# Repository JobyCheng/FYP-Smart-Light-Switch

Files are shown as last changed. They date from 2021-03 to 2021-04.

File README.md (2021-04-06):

# FYP - Smart Light Switch

This is the repo for Group SS04a-20 Final Year Project.

`/Switch` contain the PlatformIO project file for the esp32 development board.

`/model` contain file related to the 3D-model for this project.

`/video` contain demo video of the product.

`node-red-config` contain JSON file for node-red

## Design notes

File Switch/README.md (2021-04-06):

# Smart Light Switch
This is a sum up file. Please update it if anything is implemented or need to be implement.

Run `python localServer.py` to have a look on the web page without any post and get function.

css may not update beacuse of cache. Press `ctrl+F5` for most window browser. `cmd+F5` for mac (not sure)

*avoid using ADC2 (Wifi use ADC2) (not checked) (from https://github.com/khoih-prog/ESPAsync_WiFiManager)*

# Feature

- [x] Access Point (when not connected to a wifi server)
- [x] DNS ( problem exist, solve it later ) (only resolve address with Suffix `.local`(?))
- [x] WIfi client
- [x] mDNS
- [x] Mobile view
- [x] Changing the Access Point password
- [x] Wifi Page ( Fishished the fundimental part, but the UI is bad )
- [x] Reset all the setting ( by entering http://esp32.local/reset with connected device )
- [x] HOME Page
- [x] Multi Switch control 
- [x] time synchronization
- [x] time scheduled task

## Time schedule method
use cron-like syntax
```
second minute hour day month weekday action
```
To simpify the case for user interface, we will change `minute`, `hour` and `action` only.

## AP Sleep
Currently ESP32 AP doesn’t support all of the power save feature defined in Wi-Fi specification. To be specific, the AP only caches unicast data for the stations connect to this AP, but doesn’t cache the multicast data for the stations. If stations connected to the ESP32 AP are power save enabled, they may experience multicast packet loss.

https://docs.espressif.com/projects/esp-idf/en/latest/esp32/api-guides/wifi.html?highlight=power%20saving

https://blog.csdn.net/Naisu_kun/article/details/86300456
http://www.iotsharing.com/2017/05/tcp-udp-ip-with-esp32.html

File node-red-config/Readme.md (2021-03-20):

# node-red config
Change the address of TX to your network boardcast address

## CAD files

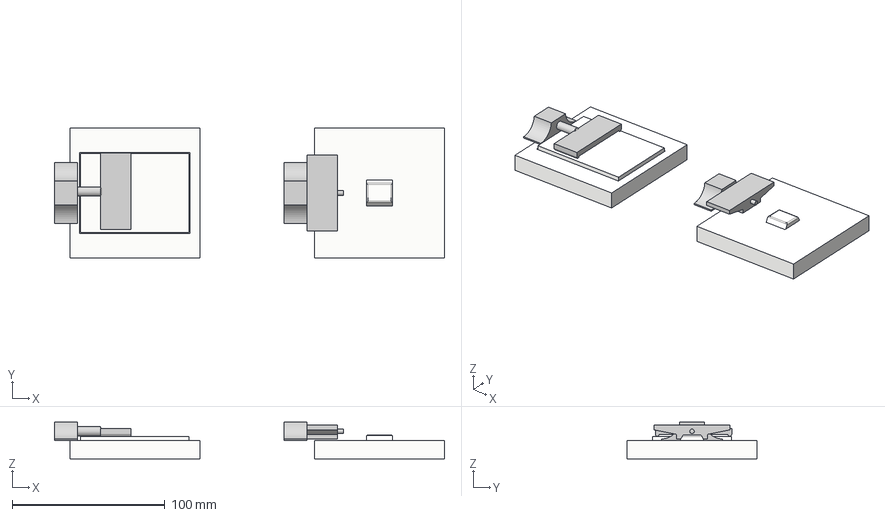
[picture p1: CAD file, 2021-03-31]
model/step&f3d/Task4.step
255.0 x 85.0 x 24.0 mm
panel
Button
Base x 2
panel_1
button_1
Moving Part_1
Moving Part_2

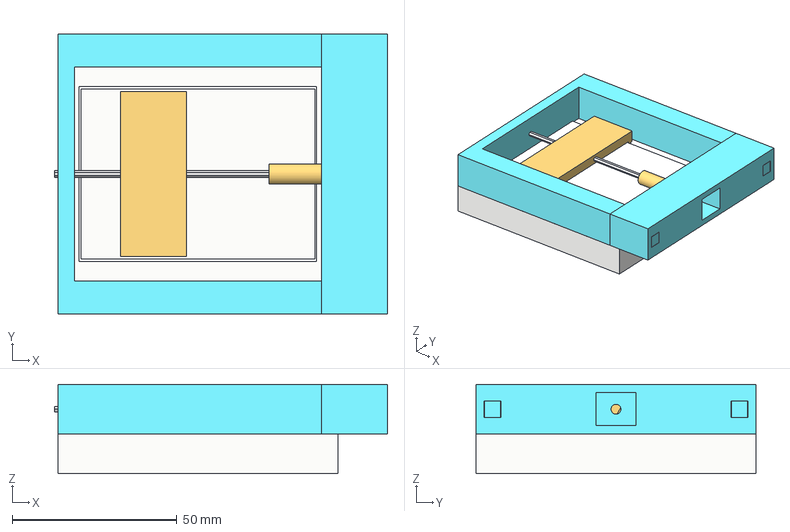
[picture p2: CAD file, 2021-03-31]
model/step&f3d/Task2-3.step
101.0 x 85.0 x 27.0 mm
Lever
panel
Button
shaft
Frame
Converter

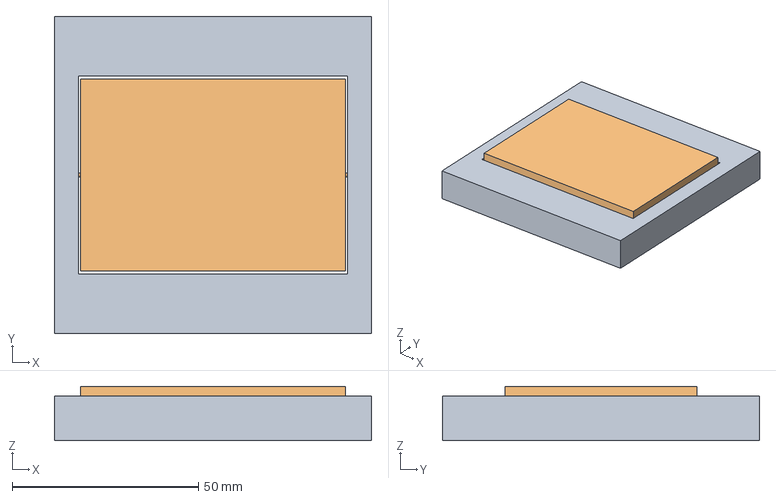
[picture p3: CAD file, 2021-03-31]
model/step&f3d/EU_switch.step
85.0 x 85.0 x 14.5 mm
panel
Button

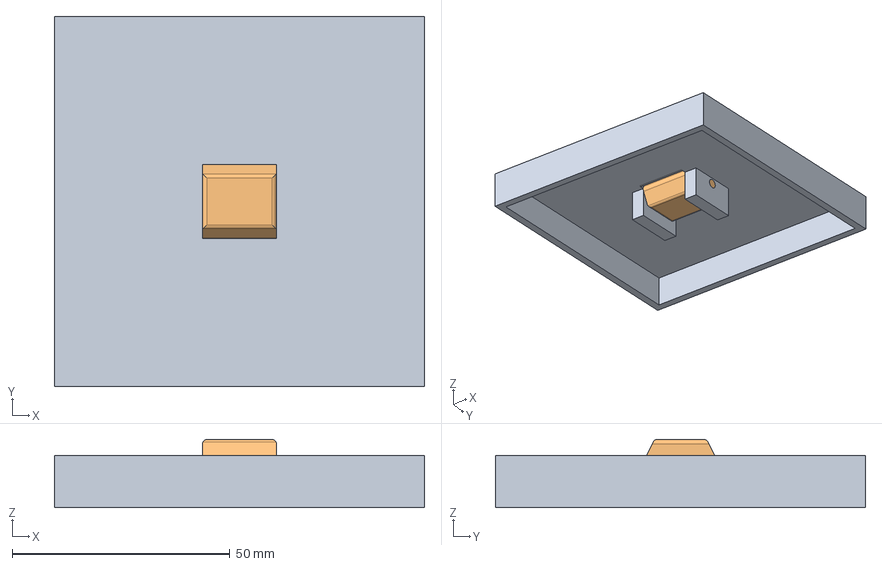
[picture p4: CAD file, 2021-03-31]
model/step&f3d/AU_switch.step
85.0 x 85.0 x 15.6 mm
panel
button

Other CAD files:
model/step&f3d/AU_switch.f3d
model/step&f3d/EU_switch.f3d
model/step&f3d/Task2-3.f3z
model/step&f3d/Task4.f3z

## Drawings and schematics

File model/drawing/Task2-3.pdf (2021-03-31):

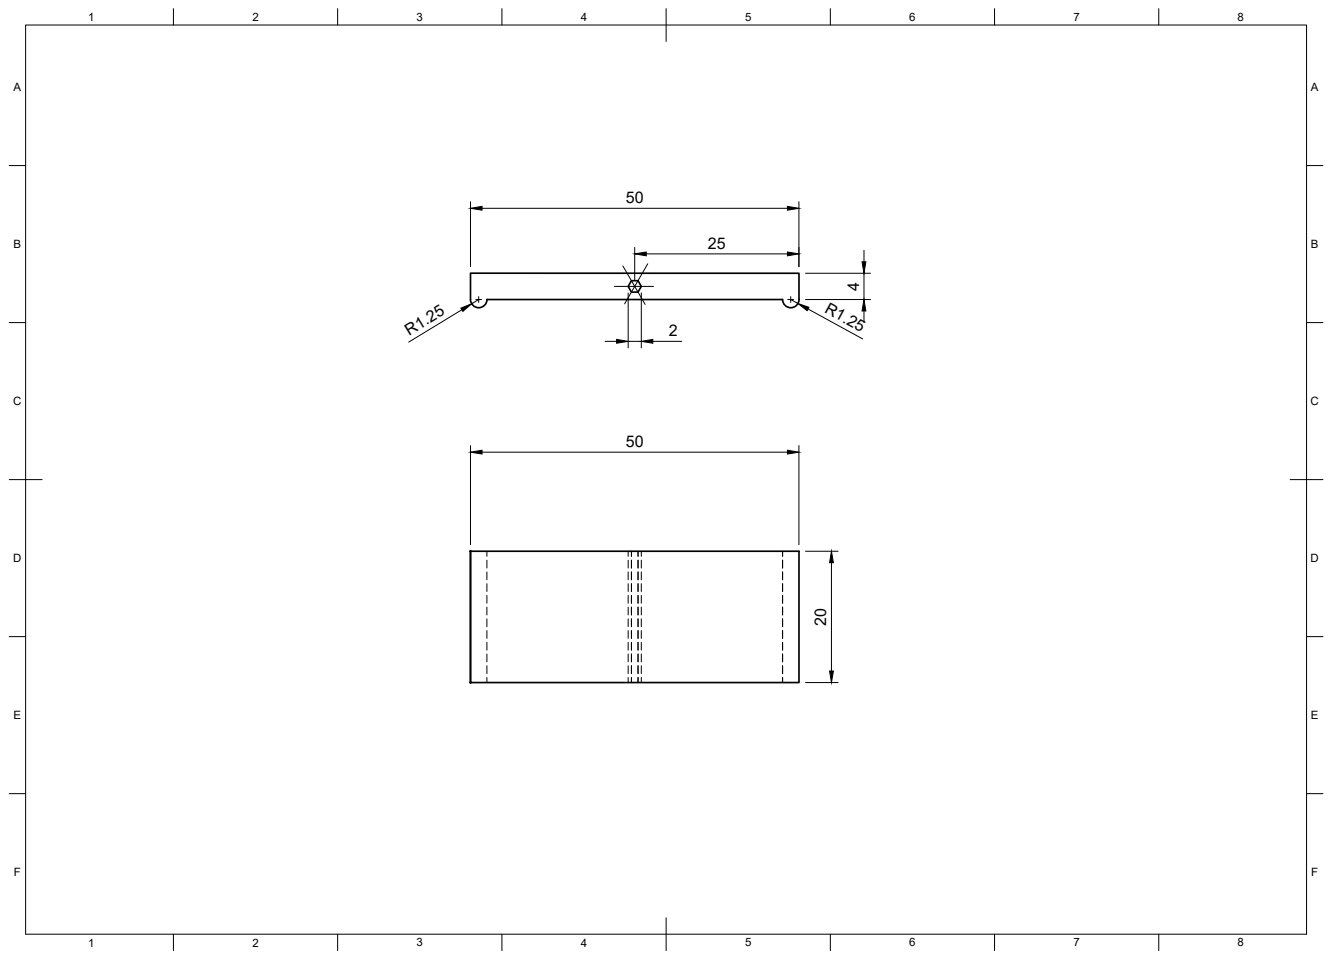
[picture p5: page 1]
8 BCDEF; ABCDEF

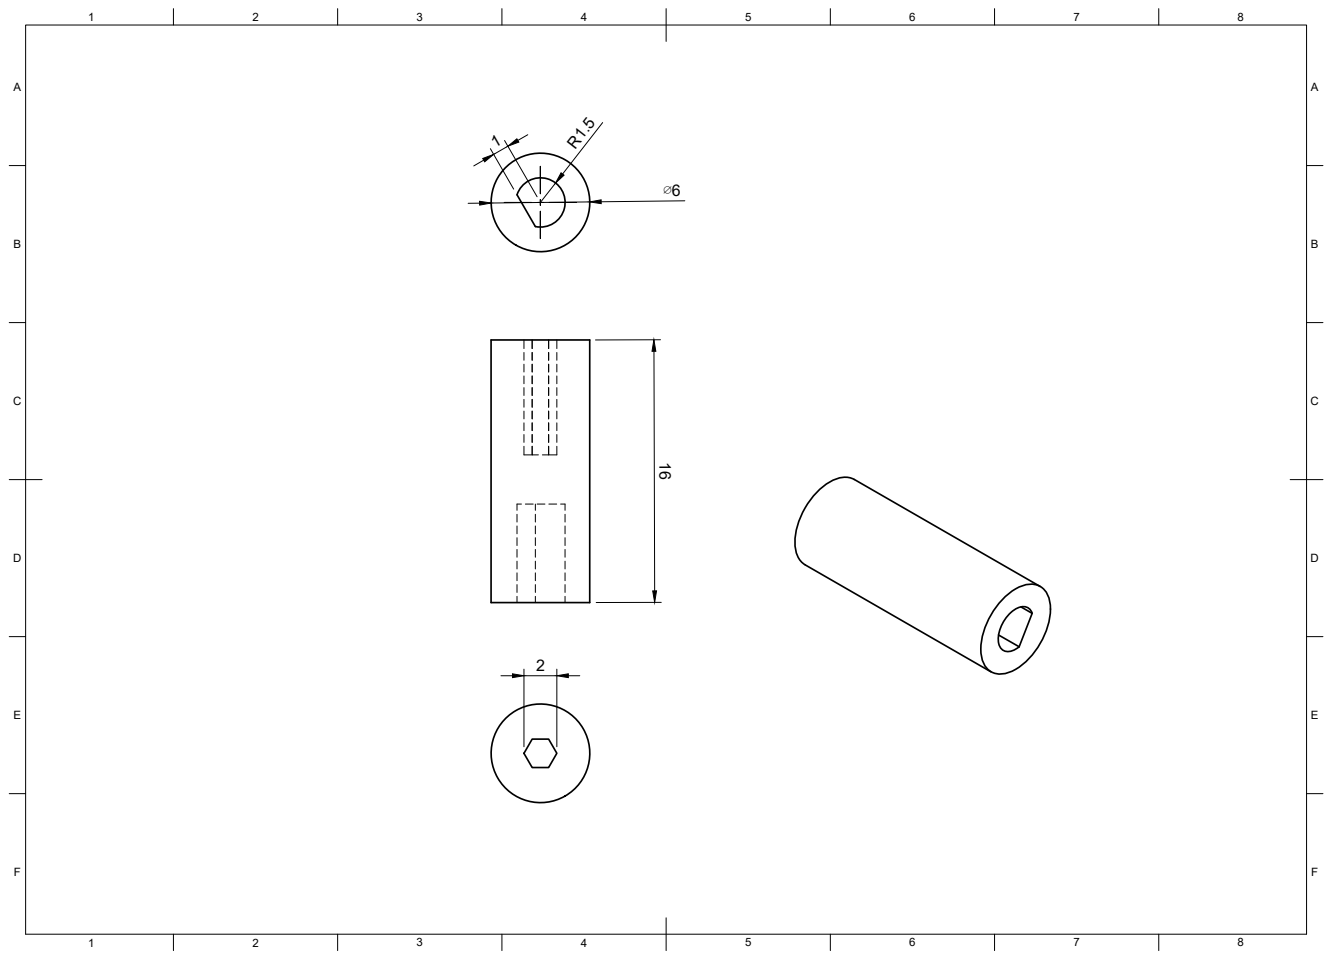
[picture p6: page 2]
8 BCDEF; ABCDEF R1.5

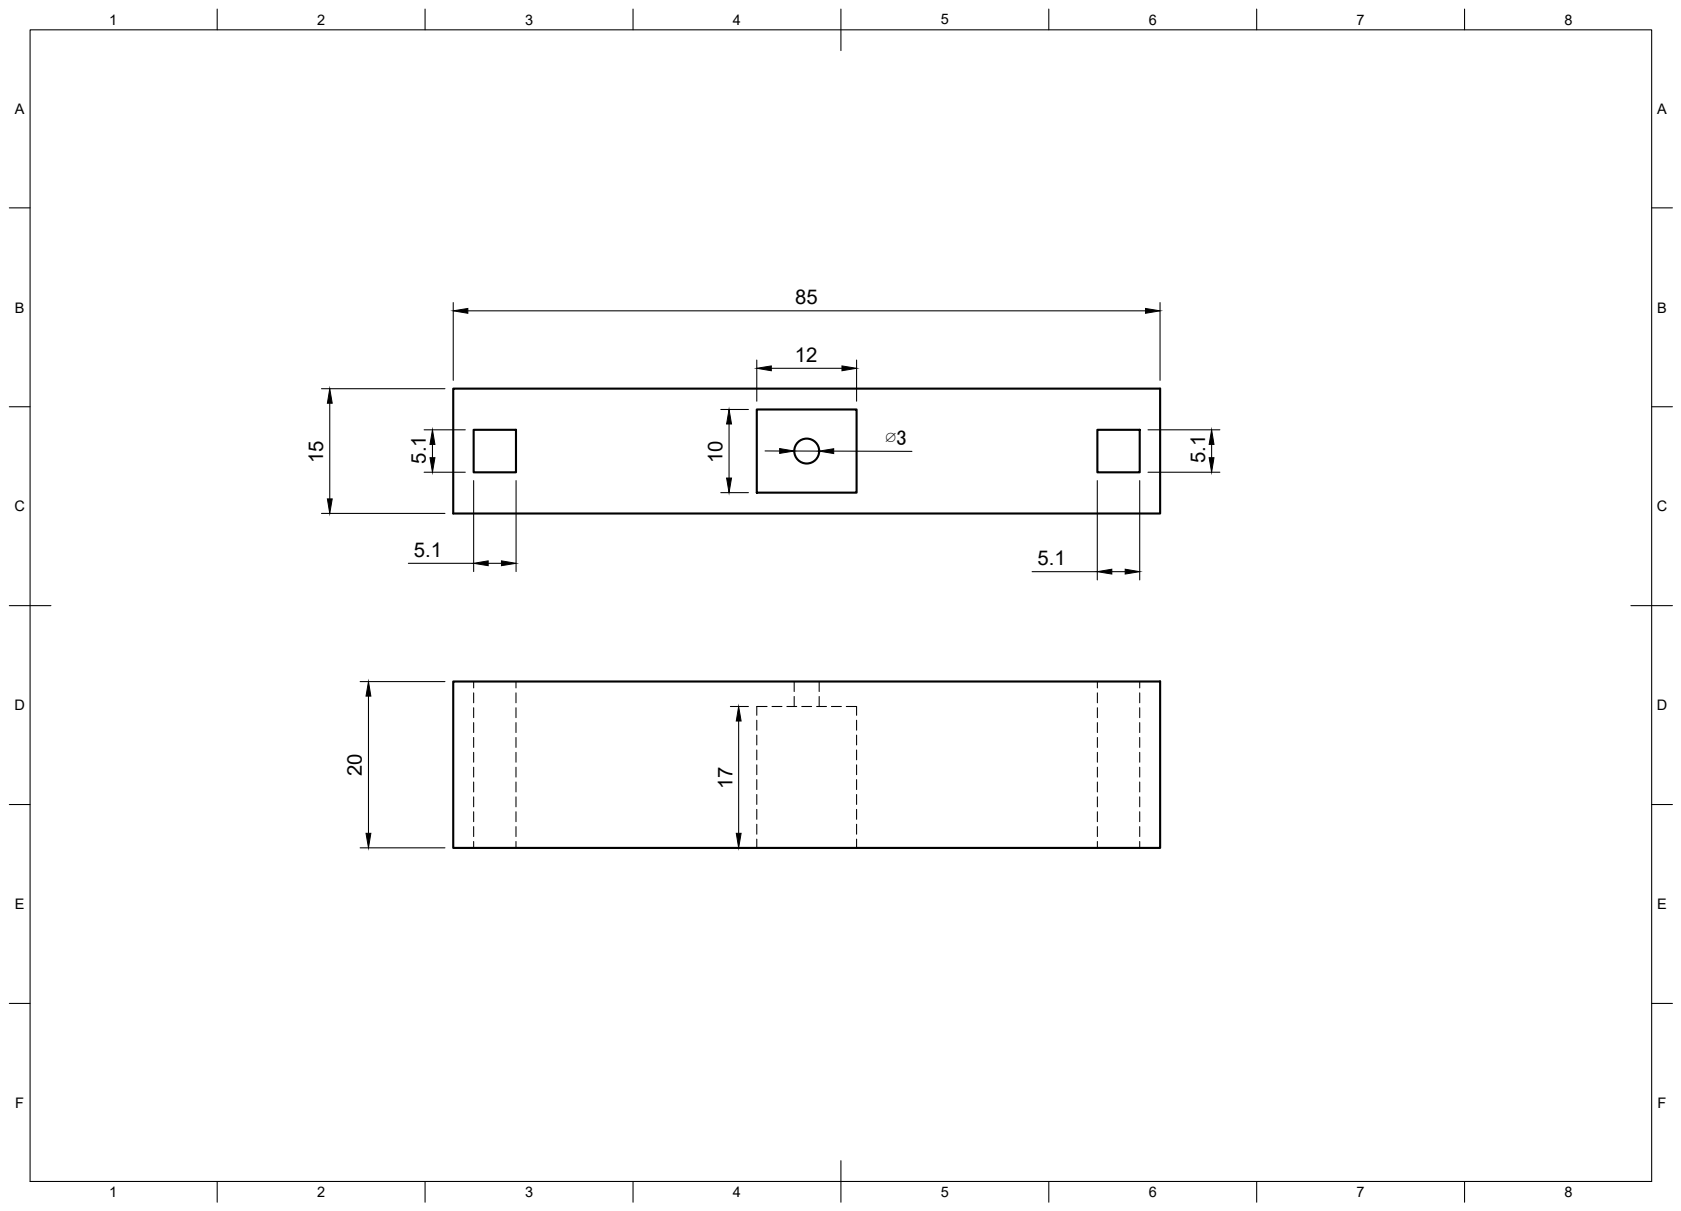
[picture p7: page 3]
8 BCDEF; ABCDEF

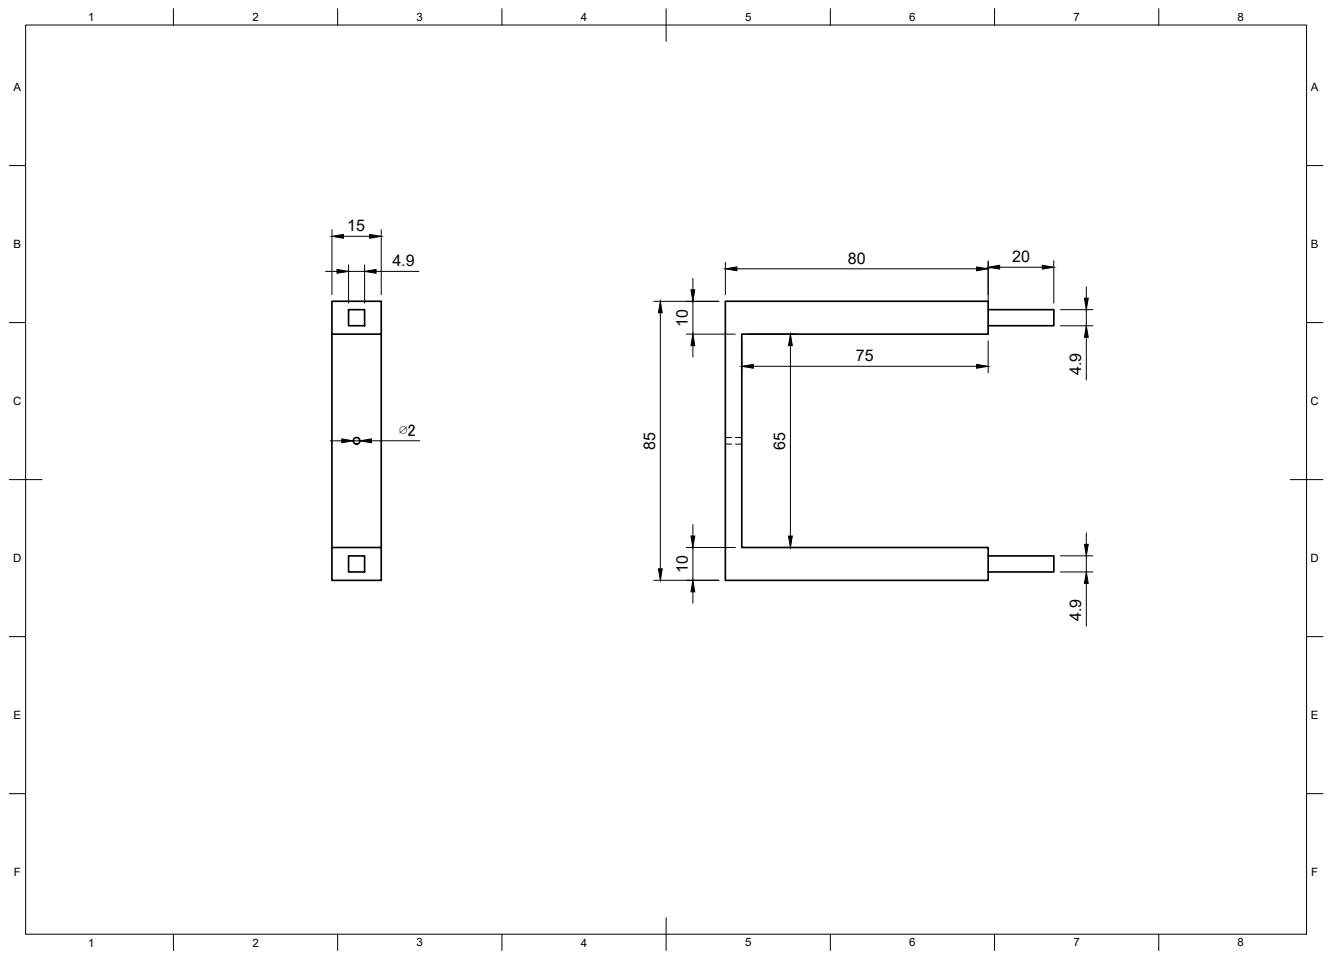
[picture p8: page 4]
8 BCDEF; ABCDEF 85

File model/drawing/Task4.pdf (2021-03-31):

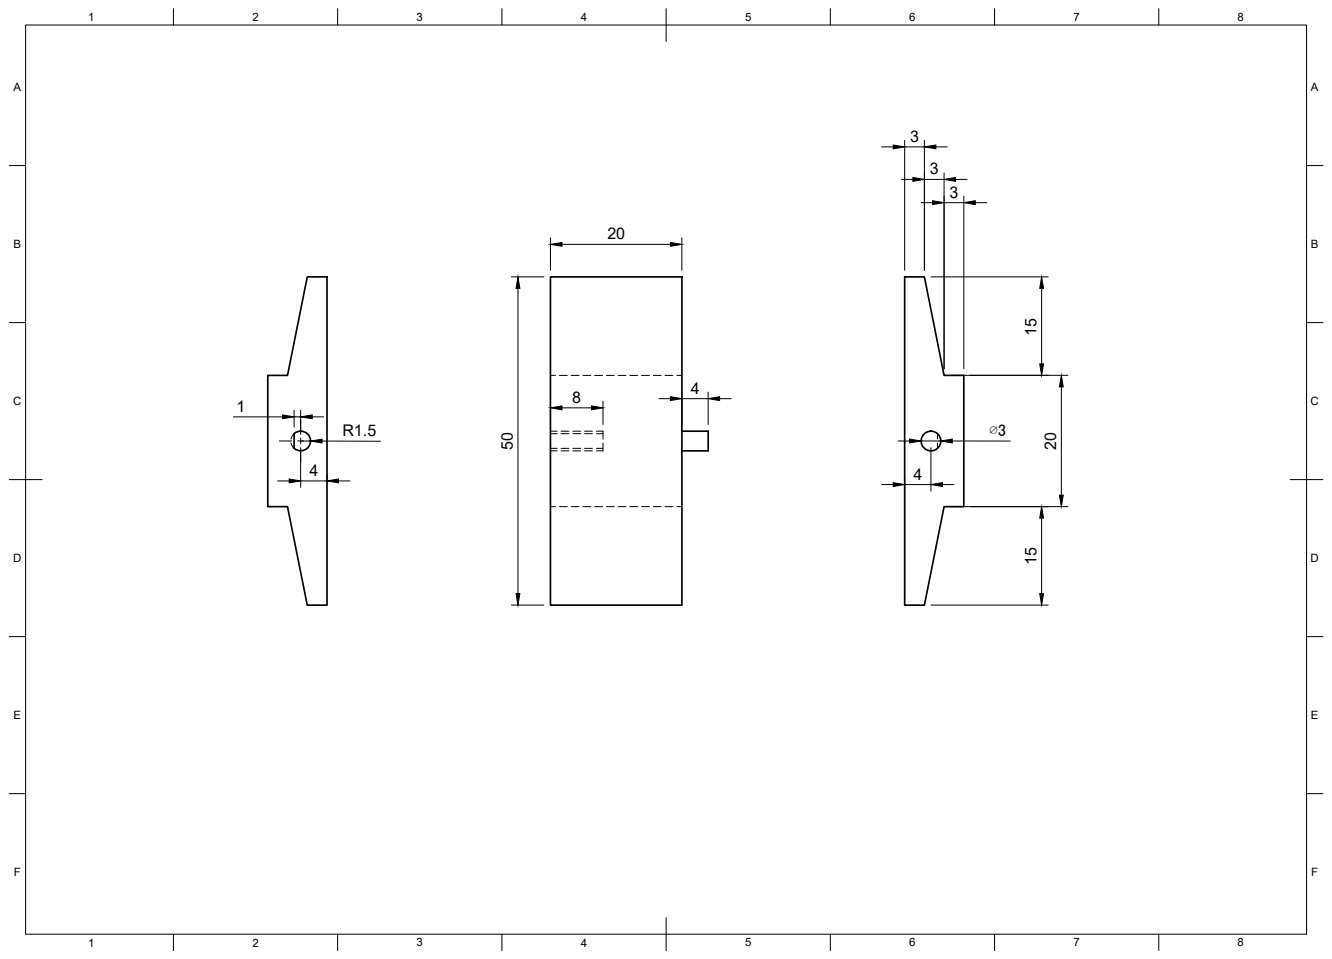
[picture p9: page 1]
8 BCDEF; ABCDEF

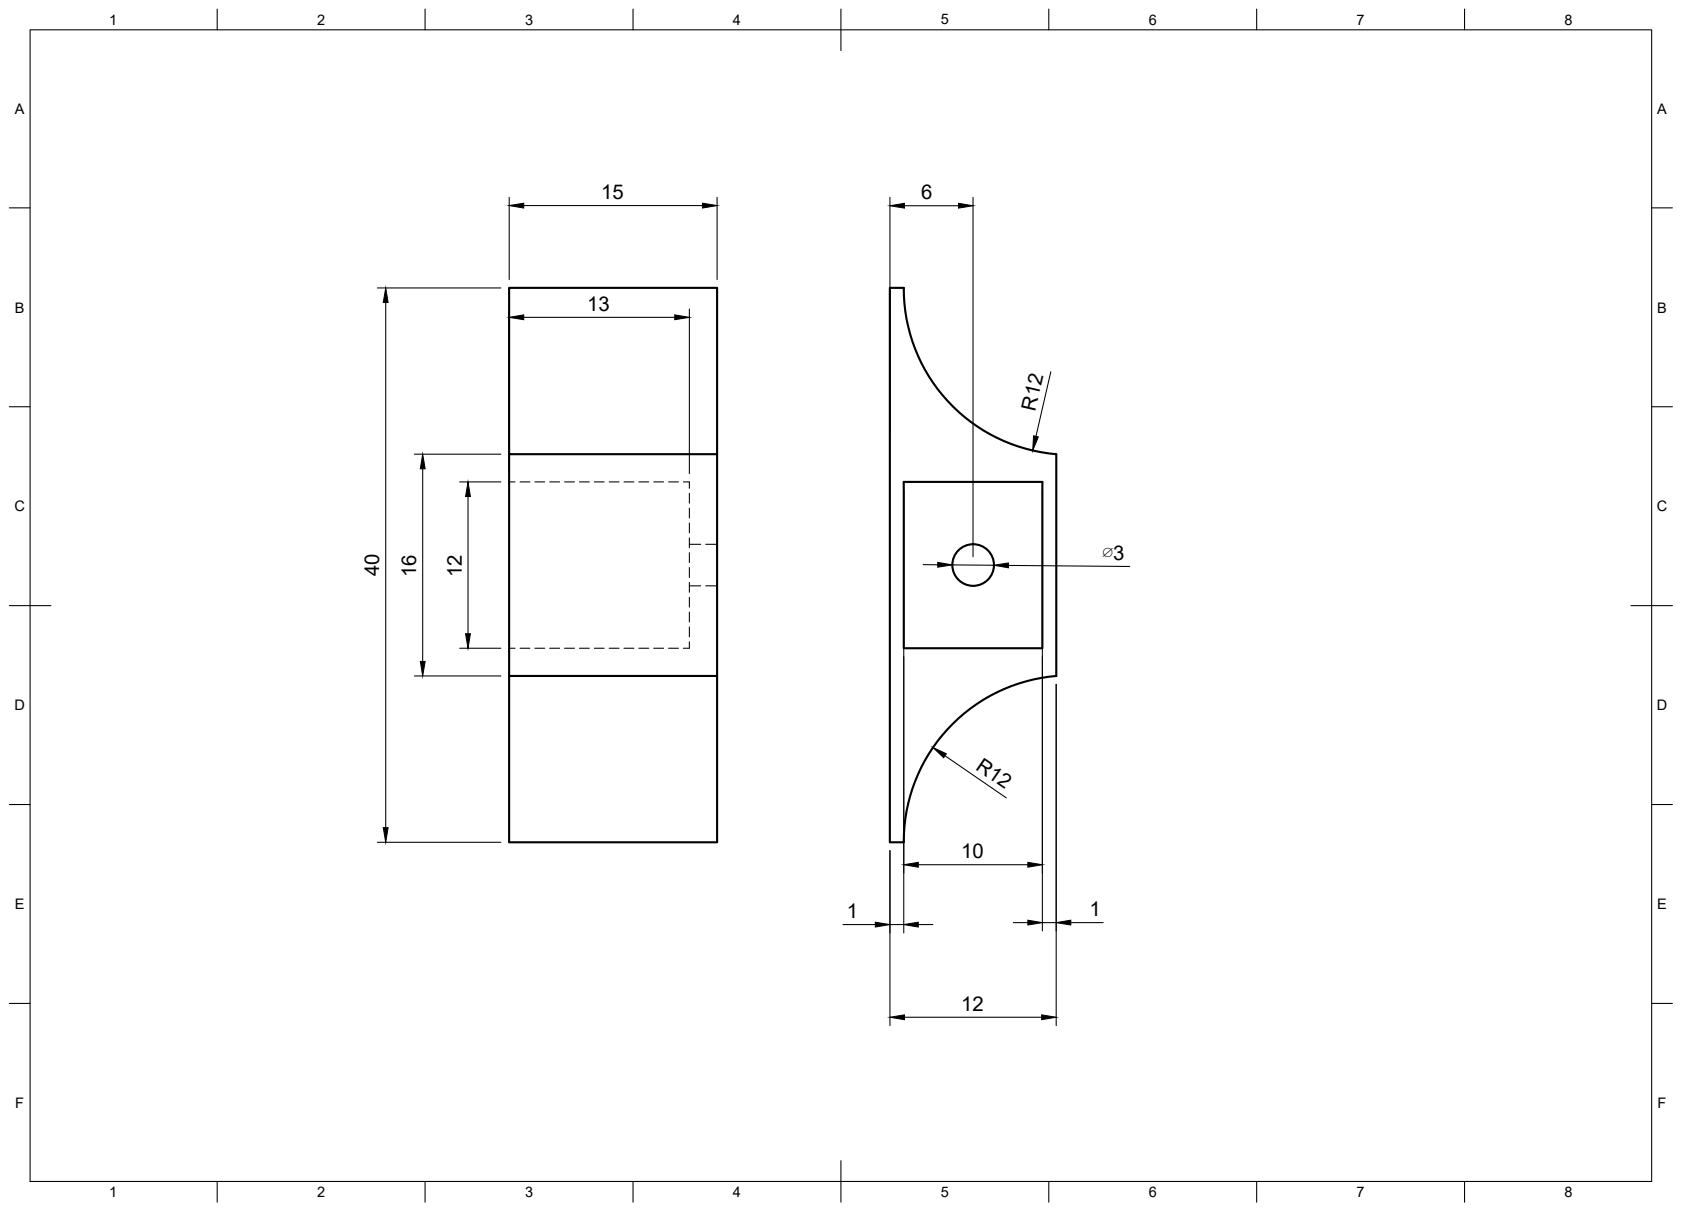
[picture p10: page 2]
8 BCDEF; ABCDEF

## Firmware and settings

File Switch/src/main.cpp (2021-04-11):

#include <Arduino.h>
#include <SPIFFS.h>

#include <Preferences.h>
#include <HTTPClient.h>

#include "service_mDNS.h"
#include "service_DNS.h"
#include "service_Wifi_AP.h"
#include "service_time_sync.h"
#include "service_cron.h"
#include "service_Wifi_client.h"
#include "service_udp.h"
#include "struct_client_entry.h"

#include <ESPAsyncWebServer.h>
#include "responses.h"

#include <CronAlarms.h>

#include "switch_gy25z.h"
#include "switch_touch.h"
#include "switch_motor.h"

/*
██╗   ██╗ █████╗ ██████╗ ██╗ █████╗ ██████╗ ██╗     ███████╗
██║   ██║██╔══██╗██╔══██╗██║██╔══██╗██╔══██╗██║     ██╔════╝
██║   ██║███████║██████╔╝██║███████║██████╔╝██║     █████╗
╚██╗ ██╔╝██╔══██║██╔══██╗██║██╔══██║██╔══██╗██║     ██╔══╝
 ╚████╔╝ ██║  ██║██║  ██║██║██║  ██║██████╔╝███████╗███████╗
  ╚═══╝  ╚═╝  ╚═╝╚═╝  ╚═╝╚═╝╚═╝  ╚═╝╚═════╝ ╚══════╝╚══════╝

*/
// product name
// will be used in name of access point, domain name of site

String PRODUCT_NAME = "esp32";

std::vector<client_entry> client_list;

enum ROLE{SERVER,CLIENT} role;
String DEVICE_ID;
String LABEL;
String MAC_ADDR;

AsyncWebServer web_server(80);
Preferences preferences;
DNSServer dns_server;
extern CronClass Cron;
extern WiFiClass WiFi;
WiFiUDP udp;

bool DNS_enabled;

unsigned long lastLoop;

/*
███████╗███████╗████████╗██╗   ██╗██████╗
██╔════╝██╔════╝╚══██╔══╝██║   ██║██╔══██╗
███████╗█████╗     ██║   ██║   ██║██████╔╝
╚════██║██╔══╝     ██║   ██║   ██║██╔═══╝
███████║███████╗   ██║   ╚██████╔╝██║
╚══════╝╚══════╝   ╚═╝    ╚═════╝ ╚═╝

*/
void setup() {
  Serial.begin(115200);
  // put your setup code here, to run once:

  pinMode(AIN1, OUTPUT);
  pinMode(AIN2, OUTPUT);
  pinMode(EN, OUTPUT);

  touchAttachInterrupt(T8, T8wasActivated, threshold);
  touchAttachInterrupt(T9, T9wasActivated, threshold);

  gy25z_init();

  preferences.begin("switchSetting");
  preferences.putBool("switchIsOn", false);
  preferences.putBool("calibrated", false);
  preferences.end();
  
  // create a id with MAC address.
  MAC_ADDR = String((unsigned long) ESP.getEfuseMac(),16);
  DEVICE_ID = MAC_ADDR;

  // get label if any
  preferences.begin("setting");
  LABEL = preferences.isKey("LABEL")?preferences.getString("LABEL"):String(DEVICE_ID);
  preferences.end();
  // Default as server, change to client if it detect a server.
  role = SERVER;

  /*
  ███╗   ██╗███████╗████████╗██╗    ██╗ ██████╗ ██████╗ ██╗  ██╗
  ████╗  ██║██╔════╝╚══██╔══╝██║    ██║██╔═══██╗██╔══██╗██║ ██╔╝
  ██╔██╗ ██║█████╗     ██║   ██║ █╗ ██║██║   ██║██████╔╝█████╔╝
  ██║╚██╗██║██╔══╝     ██║   ██║███╗██║██║   ██║██╔══██╗██╔═██╗
  ██║ ╚████║███████╗   ██║   ╚███╔███╔╝╚██████╔╝██║  ██║██║  ██╗
  ╚═╝  ╚═══╝╚══════╝   ╚═╝    ╚══╝╚══╝  ╚═════╝ ╚═╝  ╚═╝╚═╝  ╚═╝
  */
  

  // Wifi
  if (wifi_client_start_with_setting()){
    // Check if there is any server in the LAN
    if (udp_start()){
      if(udp_checkServer(2000)){
        Serial.println("Server found");
        udp_stop();
        role = CLIENT;
      }else{
        // keep listening to port 8000
        mDNS_start(PRODUCT_NAME);
      }
    }

    Serial.println("Role:\t\t"+((role == CLIENT)?String("Client"):String("Server")));
    Serial.println("ID:\t\t"+DEVICE_ID);
    Serial.println("label:\t\t"+LABEL);
    
    if(time_sync_start()){  // Start cron if time sync is check.
      cron_load_from_setting();
    }
    
  }else{
    //Access point
    wifi_ap_start(PRODUCT_NAME+"-"+DEVICE_ID);
    //DNS
    DNS_enabled = DNS_start("*", WiFi.softAPIP());
    //if(DNS_enabled){t_DNS_request.enable();}
  }

  client_list.push_back({DEVICE_ID,LABEL,WiFi.localIP()});


  /*
  ██╗    ██╗███████╗██████╗ ███████╗███████╗██████╗ ██╗   ██╗███████╗██████╗
  ██║    ██║██╔════╝██╔══██╗██╔════╝██╔════╝██╔══██╗██║   ██║██╔════╝██╔══██╗
  ██║ █╗ ██║█████╗  ██████╔╝███████╗█████╗  ██████╔╝██║   ██║█████╗  ██████╔╝
  ██║███╗██║██╔══╝  ██╔══██╗╚════██║██╔══╝  ██╔══██╗╚██╗ ██╔╝██╔══╝  ██╔══██╗
  ╚███╔███╔╝███████╗██████╔╝███████║███████╗██║  ██║ ╚████╔╝ ███████╗██║  ██║
   ╚══╝╚══╝ ╚══════╝╚═════╝ ╚══════╝╚══════╝╚═╝  ╚═╝  ╚═══╝  ╚══════╝╚═╝  ╚═╝
  */
  
  if(!SPIFFS.begin(true)){
    Serial.println("An Error has occurred while mounting SPIFFS");
    return;
  }
  
  /*
  ██████╗ ███████╗ ██████╗ ██╗   ██╗███████╗███████╗████████╗
  ██╔══██╗██╔════╝██╔═══██╗██║   ██║██╔════╝██╔════╝╚══██╔══╝
  ██████╔╝█████╗  ██║   ██║██║   ██║█████╗  ███████╗   ██║
  ██╔══██╗██╔══╝  ██║▄▄ ██║██║   ██║██╔══╝  ╚════██║   ██║
  ██║  ██║███████╗╚██████╔╝╚██████╔╝███████╗███████║   ██║
  ╚═╝  ╚═╝╚══════╝ ╚══▀▀═╝  ╚═════╝ ╚══════╝╚══════╝   ╚═╝
  */

 if(role == SERVER){
  web_server.serveStatic("/", SPIFFS, "/").setDefaultFile("index.html");

  web_server.on("/wifiStauts",HTTP_GET,responses_wifiStauts);
  web_server.on("/SSIDlist", HTTP_GET,responses_SSIDlist);
  web_server.on("/wifi_setting",HTTP_POST,responses_wifi_setting);
   
  web_server.on("/getClient",HTTP_GET,responses_getClient);
 }

  web_server.on("/reset",HTTP_GET,responses_reset);
  web_server.on("/restart",HTTP_GET,responses_restart);

  web_server.on("/on",HTTP_GET,responses_on);
  web_server.on("/off",HTTP_GET,responses_off);

  web_server.on("/getSchedule",HTTP_GET,responses_getSchedule);
  web_server.on("/setSchedule",HTTP_POST,responses_setSchedule);

  web_server.on("/status",HTTP_GET,responses_status);
  web_server.on("/setLabel",HTTP_GET,responses_setLabel);

  web_server.on("/calibration",HTTP_GET,responses_calibration);  

  web_server.begin();
  
  lastLoop = millis();
}

/*
██╗      ██████╗  ██████╗ ██████╗
██║     ██╔═══██╗██╔═══██╗██╔══██╗
██║     ██║   ██║██║   ██║██████╔╝
██║     ██║   ██║██║   ██║██╔═══╝
███████╗╚██████╔╝╚██████╔╝██║
╚══════╝ ╚═════╝  ╚═════╝ ╚═╝

*/
void loop() {
  // put your main code here, to run repeatedly:
  Cron.delay();
  if (DNS_enabled){dns_server.processNextRequest();};
  if (role==SERVER && WiFi.isConnected()){udp_handle_next_packet();}
  if (role==CLIENT && (millis()>lastLoop+1000*60)){udp_boardcast_message();lastLoop=millis();}
  touch_manual();
}

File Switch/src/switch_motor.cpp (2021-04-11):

#include "switch_motor.h"


const int AIN1 = 25; 
const int AIN2 = 26; 
const int EN = 27;
volatile float T8Roll;
volatile float T9Roll;
bool calManual = false;


//clk = t8
//anticlk = t9

void on(){
    //Serial.print("Switch On");
    
    preferences.begin("switchSetting"); 
    if(preferences.getBool("T8IsOn", false)){
        turnClkwise();
    }else{
        turnAntiClkwise();
    }
    preferences.end();
}

void off(){
    //Serial.print("off");

    preferences.begin("switchSetting");
    if(preferences.getBool("T8IsOn", false)){
        turnAntiClkwise();
    }else{
        turnClkwise();
    }
    preferences.end();
}

void calibrate(){
    //Serial.println("test");
    delay(700);
    bool cal = true;
    bool calT8 = false;
    bool calT9 = false;
    digitalWrite(EN, HIGH);
    while (cal){
        if(triggeredT8 && !triggeredT9){
            //Serial.println("T8");
            digitalWrite(AIN1, LOW);
            digitalWrite(AIN2, HIGH);
            if(touchRead(T8)>threshold){
                digitalWrite(AIN1, LOW);
                digitalWrite(AIN2, LOW);
                triggeredT8 = false;
                calT8 = true;
                T8Roll = gy25z_getRoll();
                delay(50);
            }
        }
        if(triggeredT9 && !triggeredT8){
            //Serial.println("T9");
            digitalWrite(AIN1, HIGH);
            digitalWrite(AIN2, LOW);
            if(touchRead(T9)>threshold){
                digitalWrite(AIN1, LOW);
                digitalWrite(AIN2, LOW);
                triggeredT9 = false;
                calT9 = true;
                T9Roll = gy25z_getRoll();
                delay(50);
            }
        }
        if(calT8 && calT9){
            delay(1);
            digitalWrite(EN, LOW);
            preferences.begin("switchSetting");
            preferences.putFloat("T8Roll",T8Roll);
            preferences.putFloat("T9Roll",T9Roll);
            if(T8Roll > T9Roll){
                preferences.putBool("T8IsOn",true);
            }else{
                preferences.putBool("T8IsOn",false);
            }
            delay(1);
            Serial.print("T8Roll: "); 
            Serial.println(preferences.getFloat("T8Roll",-1));
            Serial.print("T9Roll: "); 
            Serial.println(preferences.getFloat("T9Roll",-1));
            Serial.print("T8IsOn:" );
            Serial.println(preferences.getBool("T8IsOn", false)?String("True"):String("False"));
            preferences.putBool("calibrated",true);
            preferences.end();
            
            cal = false;
            calManual = true;
            Serial.println("end cal");
        }
    }
    return;
}

void turnClkwise(){
    preferences.begin("switchSetting");
    if(preferences.getBool("calibrated",false)){
        preferences.putBool("switchIsOn", (preferences.getBool("T8IsOn", false)?true:false));
        digitalWrite(EN, HIGH);
        float current_roll = gy25z_getRoll();
        float target_roll = preferences.getFloat("T8Roll",-1);
        digitalWrite(AIN1, LOW);
            digitalWrite(AIN2, HIGH);
        if(abs(current_roll - target_roll)<=2){
            digitalWrite(EN, LOW);
        }
    }else{
        Serial.println("Plz calibrate first");
    }
    preferences.end();
}

void turnAntiClkwise(){
    preferences.begin("switchSetting");
    if(preferences.getBool("calibrated",false)){
        preferences.putBool("switchIsOn", (preferences.getBool("T8IsOn", false)?false:true));
        digitalWrite(EN, HIGH);
        float current_roll = gy25z_getRoll();
        float target_roll = preferences.getFloat("T9Roll",-1);
        digitalWrite(AIN1, HIGH);
        digitalWrite(AIN2, LOW);
        if(abs(current_roll - target_roll)<=2){
            digitalWrite(EN, LOW);
        }
    }else{
        Serial.println("Plz calibrate first");
    }
    preferences.end();
}

void touch_manual() {
  if (triggeredT8 && calManual){
    triggeredT8 = false;
    if (touchIntervalComp(lastT8)){
      //Serial.println("turn anticlkwise");
      turnClkwise();
      lastT8 = millis();
    }
  }

  if (triggeredT9 && calManual){
    triggeredT9 = false;
    if (touchIntervalComp(lastT9)){
      //Serial.println("turn clkwise");
      turnAntiClkwise();
      lastT9 = millis();
    }
  }
}

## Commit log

2021-02-15 Add lines for power saving and restart machine
2021-02-24 Adding the switch table on the web site
2021-02-25 Force platformIO to use the v3.3 framework & fix problem by that
2021-03-12 Basic frame and UI for scheduled task
2021-03-12 The remove function fail, new method implemented
    [main.cpp]
2021-03-13 Minor fix for multi switch support
2021-03-13 Prepare for multi switch control
2021-03-13 Moving all responses to "responses.h" & update multi-switch control code
2021-03-14 More update to multi-switch control
2021-03-16 multi-switch related
2021-03-17 multi-switch related
    Should be working tested with node-red
2021-03-17 update incomplete switch_gy25z/touch/motor
2021-03-17 minor fix for home page
    [main.cpp]
2021-03-17 Fixing the reply message problem
    [main.cpp, service_udp.cpp]
2021-03-18 Add button for Calibration
2021-03-19 rewriting upd without "AsyncUDP"
    Function like localIP() and remoteIP() is not working.
    [main.cpp, service_udp.cpp]
2021-03-21 adding drawing and model file
    [AU_switch.f3d, AU_switch.step, EU_switch.f3d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]
2021-04-06 update switch_gy25z/motor.h & .cpp, main.cpp, responses.cpp, service_cron.cpp
2021-04-11 update switch_motor.h .cpp, switch_motor.cpp, switch_gy25z.cpp, main.cpp, responses.cpp
